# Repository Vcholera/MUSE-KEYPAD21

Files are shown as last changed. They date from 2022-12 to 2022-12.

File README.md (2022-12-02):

# MUSE-KEYPAD21

一个基于GMK固件的21按键/2旋转编码器/1钮子开关的RGB数字小键盘

## 键盘详情

### 设计情况
此键盘的定位为常规87配列的扩充键盘，因此在设计上极大地保留了数字键盘按键区域，同时在数字区域上方添加了4个常用快捷按键，以及增加了两个旋转编码器和1个钮子开关用于调节音量/静音/屏幕亮度/切换歌曲/暂停播放音乐等功能。

在设计之初，为了方便调试（主要是担心会失败），将整个键盘分了两块PCB板子打印，一块为Atmega32U4的最小系统板，将所有IO端口引出，同时设置了Type-C接口；另一块为键盘按键主体部分，用于焊接RGB灯珠、热插拔、编码器灯，两块板子用排针排母连接。

### 芯片选择
芯片选择了QMK固件中最常用的Atmega32U4

## 键位详情

### 21按键
1. 保留keypad常规数字区的按键（0-9、 +-*/.、 回车），将Num Lock按键替换为图层切换按键
2. 增加了4个常用按键（剪切、复制、粘贴、撤销）

### 2旋转编码器
1. 选择EC11旋转编码器，支持按下
2. 两个旋转编码器在不同图层中有不同的表现

### 1钮子开关
设置钮子开关的原因是，我希望能增加一个物理的切歌开关，因此选择了自恢复三角钮子开关MTS123

### 图层
本键盘共三个图层，分别为：
    · 基础数字键图层，即原本keypad数字键盘按键+音量调节编码器1（按键静音）+屏幕亮度调节编码器2（按键暂停歌曲）+上一曲/下一曲钮子开关
    · 游戏图层，将原本的7894561230.+ Enter 分别替换为qweasdzxc Ctrl Alt r Space，编码器1改为RGB灯光亮度调节（按键关闭灯光），编码器2改为鼠标滚轮（按键静音）
    · RGB光效图层，将原数字区（0-9）改为10个RGB特效选择，Enter改为全部灯光效果循环切换，+与-为RGB饱和度修改，编码器1为RGB色相修改，编码器2为RGB亮度修改（按键关闭RGB背光）

## 文件介绍

### 3D Models
SolidWorks模型文件，是键盘的顶盖、定位板和底盖的模型文件（暂时有问题）

### Firmware
基于QMK框架的固件文件，文件夹内含有HEX固件，可以利用QMK Toolbox直接刷写（请勿直接刷写via固件）；

代码部分的使用方法：

1. 克隆qmk仓库至本地
2. 将文件夹`kb`放入`qmk-firmware\keyboards`
3. 根据QMK文档生成和刷写qmk固件

注意：via版本固件没有写好，因此暂时不支持via，请勿使用via版本hex固件刷写键盘

### Hardware
PCB的制作利用了嘉立创EDA Pro版本制作（可以白嫖Atmega32U4板），可以直接导入嘉立创EDA Pro版；同时提供了两块板子的Gerber文件，可以直接拿去PCB打印

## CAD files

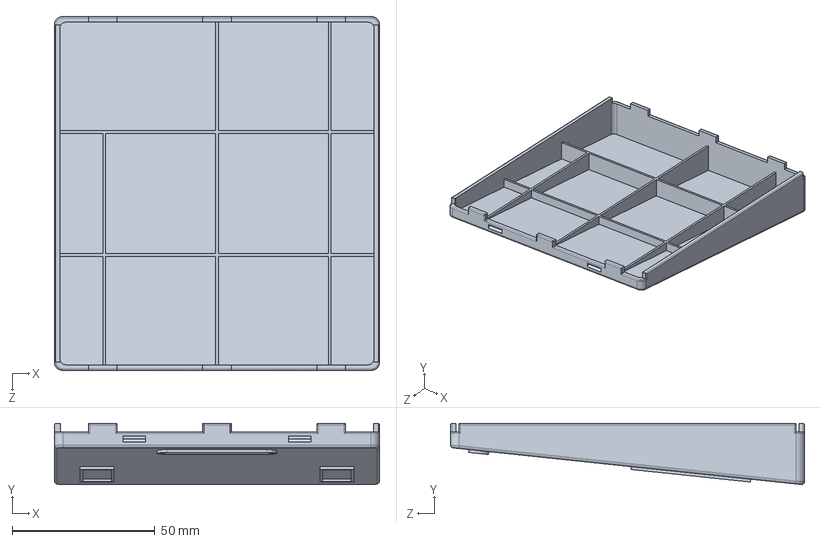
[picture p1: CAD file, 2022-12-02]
3D Models/底盖.SLDPRT
114.0 x 21.4 x 124.0 mm

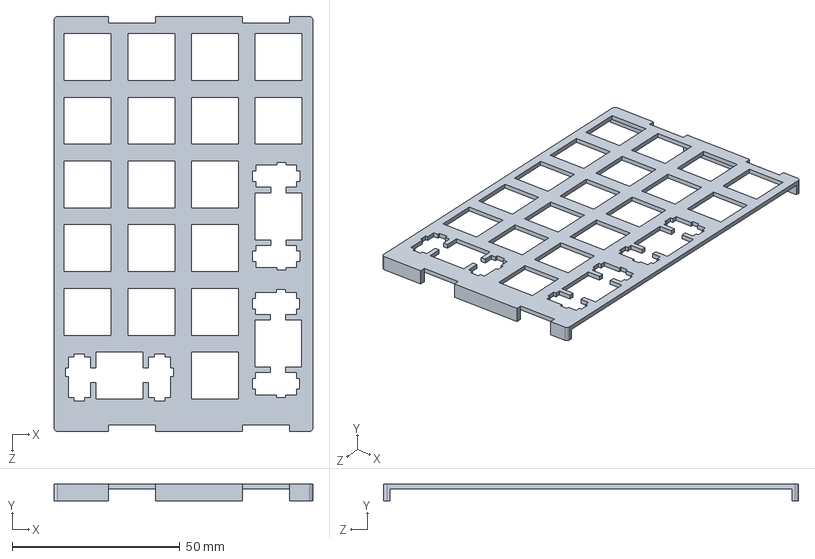
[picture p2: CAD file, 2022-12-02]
3D Models/定位板.SLDPRT
77.2 x 5.00 x 123.8 mm

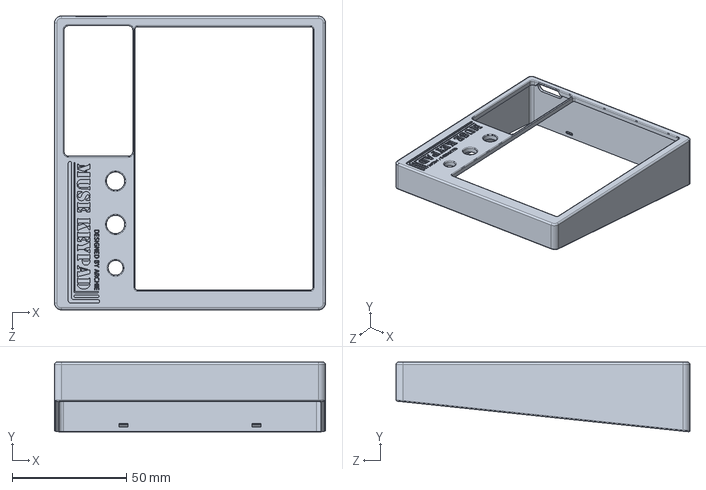
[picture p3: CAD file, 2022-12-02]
3D Models/顶盖.SLDPRT
118.4 x 30.4 x 128.4 mm

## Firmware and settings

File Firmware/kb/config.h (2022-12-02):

#ifndef CONFIG_H
#define CONFIG_H

#include "config_common.h"

/* USB Device descriptor parameter */
#define VENDOR_ID       0x5948  //YH IN ASCII
#define PRODUCT_ID      0x6060
#define DEVICE_VER      0x0001
#define MANUFACTURER    MUSE KEYBOARD
#define PRODUCT         MUSE KEYPAD

/* key matrix size */
#define MATRIX_ROWS 6
#define MATRIX_COLS 5

/* key matrix pins */
#define MATRIX_ROW_PINS { B0, B1, B2, B3, B4, B5 }
#define MATRIX_COL_PINS { D4, D5, D6, D7, E6 }

/* COL2ROW or ROW2COL */
#define DIODE_DIRECTION COL2ROW

/* number of backlight levels */
#define BACKLIGHT_PIN B6
#ifdef BACKLIGHT_PIN
#define BACKLIGHT_LEVELS 3
#endif

/* Set 0 if debouncing isn't needed */
#define DEBOUNCE 5

/* Mechanical locking support. Use KC_LCAP, KC_LNUM or KC_LSCR instead in keymap */
#define LOCKING_SUPPORT_ENABLE

/* Locking resynchronize hack */
#define LOCKING_RESYNC_ENABLE

/* key combination for command */
#define IS_COMMAND() ( \
    keyboard_report->mods == (MOD_BIT(KC_LSHIFT) | MOD_BIT(KC_RSHIFT)) \
)

/* prevent stuck modifiers */

#define RGB_DI_PIN B7
#ifdef RGB_DI_PIN

#define RGBLIGHT_EFFECT_ALTERNATING
#define RGBLIGHT_EFFECT_BREATHING
#define RGBLIGHT_EFFECT_CHRISTMAS
#define RGBLIGHT_EFFECT_KNIGHT
#define RGBLIGHT_EFFECT_RAINBOW_MOOD
#define RGBLIGHT_EFFECT_RAINBOW_SWIRL
#define RGBLIGHT_EFFECT_RGB_TEST
#define RGBLIGHT_EFFECT_SNAKE
#define RGBLIGHT_EFFECT_STATIC_GRADIENT
#define RGBLIGHT_EFFECT_TWINKLE

/* RGB LED Conversion macro from physical array to electric array */
#define LED_LAYOUT( \

  	     L01, L02, L03, L04, \
	     L11, L12, L13, L14, \
	     L21, L22, L23, L24, \
	L30, L31, L32, L33,      \
	L40, L41, L42, L43, L44, \
	L50, L51, L52, L53       \
) { \
	{        L01,   L02,   L03,   L04 }, \
	{        L11,   L12,   L13,   L14 }, \
	{        L21,   L22,   L23,   L24 }, \
	{ L30,   L31,   L32,   L33,       }, \
	{ L40,   L41,   L42,   L43,   L44 }, \
	{ L50,   L51,   L52,   L53,       }  \
}

/* RGB LED logical order map */
/* Top->Bottom, Right->Left */
#define RGBLIGHT_LED_MAP LED_LAYOUT( \
        0,  1,  2,  3,      \
        7,  6,  5,  4,      \
        8,  9,  10, 11,     \
    24, 14, 13, 12,         \
    23, 15, 16, 17, 18,     \
    22, 21, 20, 19          )


#define RGBLIGHT_SLEEP

#define RGBLED_NUM 24
#define RGBLIGHT_HUE_STEP 8
#define RGBLIGHT_SAT_STEP 8
#define RGBLIGHT_VAL_STEP 8

#endif

/*ENCODER*/

//#define ENCODERS 2
//#define ENCODERS_CW_KEY  { { 0, 0 }, { 0, 1 } }
//#define ENCODERS_CCW_KEY { { 4, 3 }, { 4, 5 } }

#define ENCODER_RESOLUTION 4
#define ENCODERS_PAD_A {F5, F1}
#define ENCODERS_PAD_B {F4, F0}



#endif

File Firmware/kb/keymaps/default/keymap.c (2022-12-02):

#include "kb.h"

enum layer_names {
    _BASE,
    _GAMEPAD,
    _RGB
};

const uint16_t PROGMEM keymaps[][MATRIX_ROWS][MATRIX_COLS] = {

	[_BASE] = LAYOUT(
		            RCTL(KC_X),     RCTL(KC_C),     RCTL(KC_V), RCTL(KC_Z),
		            TO(_GAMEPAD),   KC_PSLS,        KC_PAST,    KC_PMNS,
		            KC_P7,          KC_P8,          KC_P9,      KC_PPLS,
		KC_MUTE,    KC_P4,          KC_P5,          KC_P6,
		KC_MPLY,    KC_P1,          KC_P2,          KC_P3,      KC_PENT,
		KC_MNXT,    KC_MPRV,        KC_P0,          KC_PDOT                 ),

	[_GAMEPAD] = LAYOUT(
		            KC_ESC,     RCTL(KC_C),     RCTL(KC_V),     RCTL(KC_Z),
		            TO(_RGB),   KC_PSLS,        KC_PAST,        KC_PMNS,
		KC_Q,       KC_W,       KC_E,           KC_R,
		RGB_TOG,    KC_A,       KC_S,           KC_D,
		KC_MUTE,    KC_Z,       KC_X,           KC_C,           KC_SPACE,
		KC_TRNS,    KC_TRNS,    KC_LCTL,        KC_LALT                     ),

	[_RGB] = LAYOUT(
		            KC_NO,      KC_NO,          KC_NO,          KC_NO,
		            TO(_BASE),  KC_NO,          KC_NO,          RGB_SAI,
		RGB_M_P,    RGB_M_B,    RGB_M_R,        RGB_SAD,
		KC_NO,      RGB_M_SW,   RGB_M_SN,       RGB_M_K,
		RGB_TOG,    RGB_M_X,    RGB_M_G,        RGB_M_T,        RGB_MOD,
		KC_TRNS,    KC_TRNS,      RGB_M_TW,       KC_NO                       ),

};

void matrix_init_user(void) {
}

void matrix_scan_user(void) {
}

bool process_record_user(uint16_t keycode, keyrecord_t *record) {
	return true;
}

void led_set_user(uint8_t usb_led) {

	if (usb_led & (1 << USB_LED_NUM_LOCK)) {

	} else {

	}

	if (usb_led & (1 << USB_LED_CAPS_LOCK)) {

	} else {

	}

	if (usb_led & (1 << USB_LED_SCROLL_LOCK)) {

	} else {

	}

	if (usb_led & (1 << USB_LED_COMPOSE)) {

	} else {

	}

	if (usb_led & (1 << USB_LED_KANA)) {

	} else {

	}

}

/*
bool encoder_update_user(uint8_t index, bool clockwise) {
    if (index == 0) {
        if (clockwise) {
            tap_code(KC_VOLU);
        } else {
            tap_code(KC_VOLD);
        }
    } else if (index == 1) {
        if (clockwise) {
            tap_code(KC_BRIU);
        } else {
            tap_code(KC_BRID);
        }
    }
    return false;
}
*/


const uint16_t PROGMEM encoder_map[][NUM_ENCODERS][2] = {
    [_BASE]    =  { ENCODER_CCW_CW(KC_VOLU, KC_VOLD),           ENCODER_CCW_CW(KC_BRIU, KC_BRID)  },
    [_GAMEPAD] =  { ENCODER_CCW_CW(RGB_VAI, RGB_VAD),           ENCODER_CCW_CW(KC_WH_U, KC_WH_D)  },
    [_RGB] =  { ENCODER_CCW_CW(RGB_HUD, RGB_HUI),           ENCODER_CCW_CW(RGB_VAI, RGB_VAD)  },
};
